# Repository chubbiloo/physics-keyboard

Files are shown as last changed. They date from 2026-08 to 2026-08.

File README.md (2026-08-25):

# physics-keyboard

A 33-key mechanical keyboard for writing physics and math.

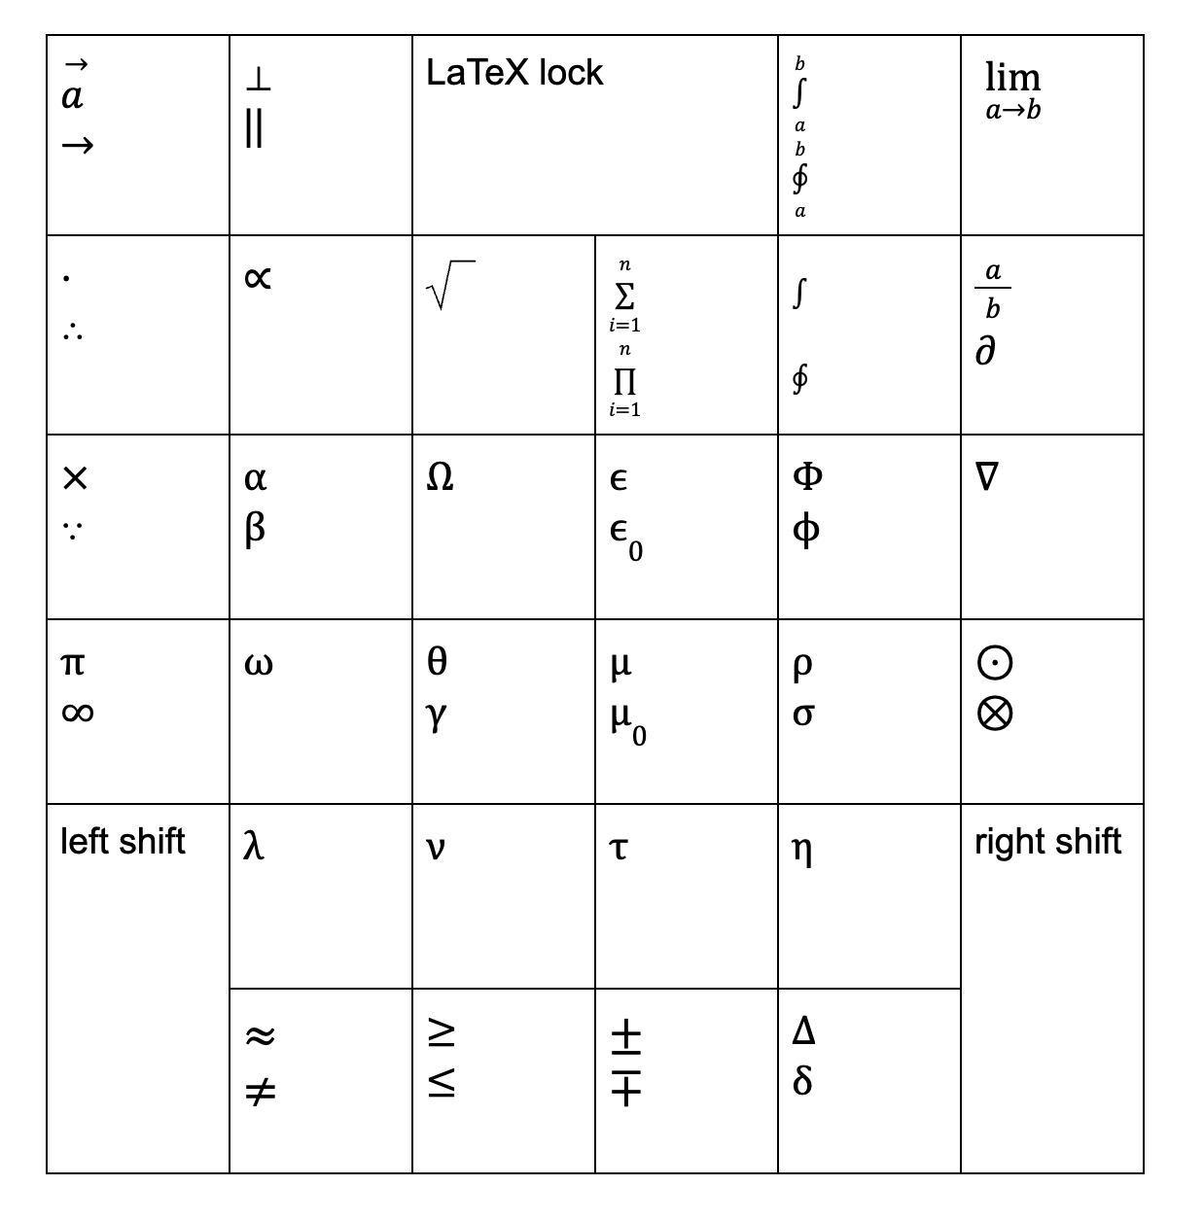
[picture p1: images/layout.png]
Layout


## Features
- Greek letter input
- Math symbol input
- Left and right shift keys allow for 53 unique characters
- Caps Lock-like key allows switching between LaTeX and plain unicode output
- Compact square shape; similar in size to a large numpad/macropad

[BOM](bom.csv)

## Tools
- PCB design: KiCad, marbastlib
- Enclosure CAD: OnShape
- Keycap lettering: Tinkercad
- Firmware: RMK 

## Motivation
In our last years of high school, we wrote several lab reports in IB Physics which required us to input mathematical equations. We built this keyboard to make that process easier, in our classes in university.

## What we learned
Before this project, we wrote our formulae in the Google Docs equation editor. This project helped us learn LaTeX, a faster and more advanced tool than what we used previously. We also learned PCB design, including best practices for routing and design rule checking.

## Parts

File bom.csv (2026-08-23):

Item | Unit Price | Count | Total Price | Link | Notes
1N4148 diode | 0.089 | 33 | 2.94 | https://www.digikey.ca/en/products/detail/onsemi/1N4148/458603
Keychron K Pro Mint switch |  | 110 | 29.99 | https://www.canadacomputers.com/en/keyboard-switches/261218/keychron-keychron-k-pro-switch-mint-110pcs-g149.html
Raspberry Pi Pico | 6.83 | 1 | 6.83 | https://www.digikey.ca/en/products/detail/raspberry-pi/SC0915/13624793
Stabilizers (7 x 2u, 1 x 6.25u) | 22.66 | 1 | 21.79 | https://www.aliexpress.com/item/1005005533734240.html
M2 heatset inserts (OD 3.5mm, L 4mm) |  | 50 | 3.16 | https://www.aliexpress.com/item/1005007946200223.html
20-pin header | 0.45 | 2 | 0.90 | https://www.digikey.ca/en/products/detail/same-sky-formerly-cui-devices/SSK01-MPH-254-A20/28772188
PCB |  | 5 | 16.94 |  | Ordered from JLCPCB
JLCPCB discounts |  |  | -13.97 |  | By applying coupon and ordering on desktop app
Aliexpress discounts |  |  | -4.00 |  | Promo code "IFP5UVCD"
JLCPCB shipping |  |  | 12.98
Digikey shipping |  |  | 15.00
Aliexpress shipping |  |  | 1.99
Subtotal |  |  | 92.56
Total including 13% HST |  |  | 104.59
All prices in CAD

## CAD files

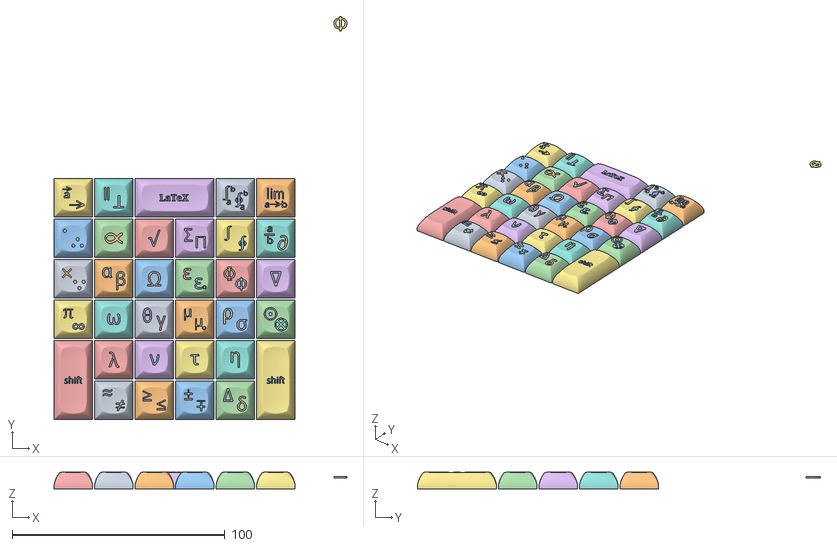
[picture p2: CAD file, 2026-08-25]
keycap-lettering/tinker.obj
137.8 x 189.6 x 7.91
obj_0
obj_1
obj_2
obj_3
obj_4
obj_5
obj_6
obj_7
obj_8
obj_9
obj_10
obj_11
obj_12
obj_13
obj_14
obj_15
obj_16
obj_17
obj_18
obj_19
obj_20
obj_21
obj_22
obj_23
obj_24
obj_25
obj_26
obj_27
obj_28
obj_29
obj_30
obj_31
obj_32
obj_33
obj_34
obj_35
obj_36
obj_37
obj_38
obj_39
obj_40
obj_41
obj_42
obj_43
obj_44
obj_45
obj_46
obj_47
obj_48
obj_49
obj_50
obj_51
obj_52
obj_53
obj_54
obj_55
obj_56
obj_57
obj_58
obj_59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

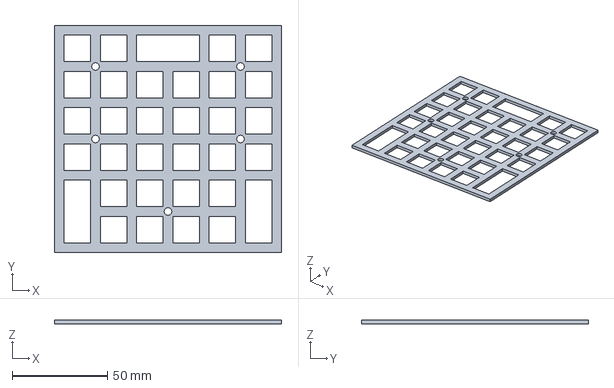
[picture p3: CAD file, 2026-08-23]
physics-keyboard-plate.step
119.3 x 119.3 x 2.00 mm

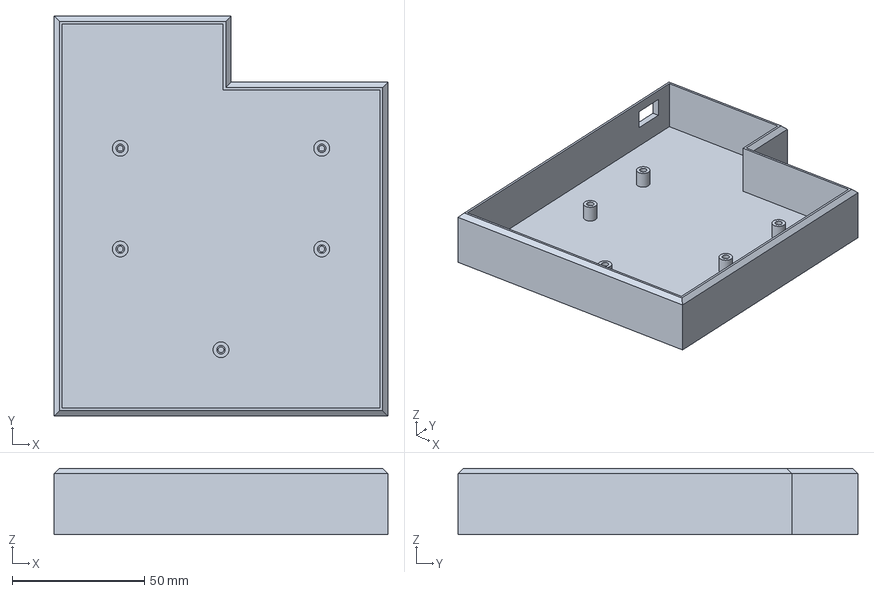
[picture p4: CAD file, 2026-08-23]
physics-keyboard-case.step
126.3 x 151.3 x 25.0 mm

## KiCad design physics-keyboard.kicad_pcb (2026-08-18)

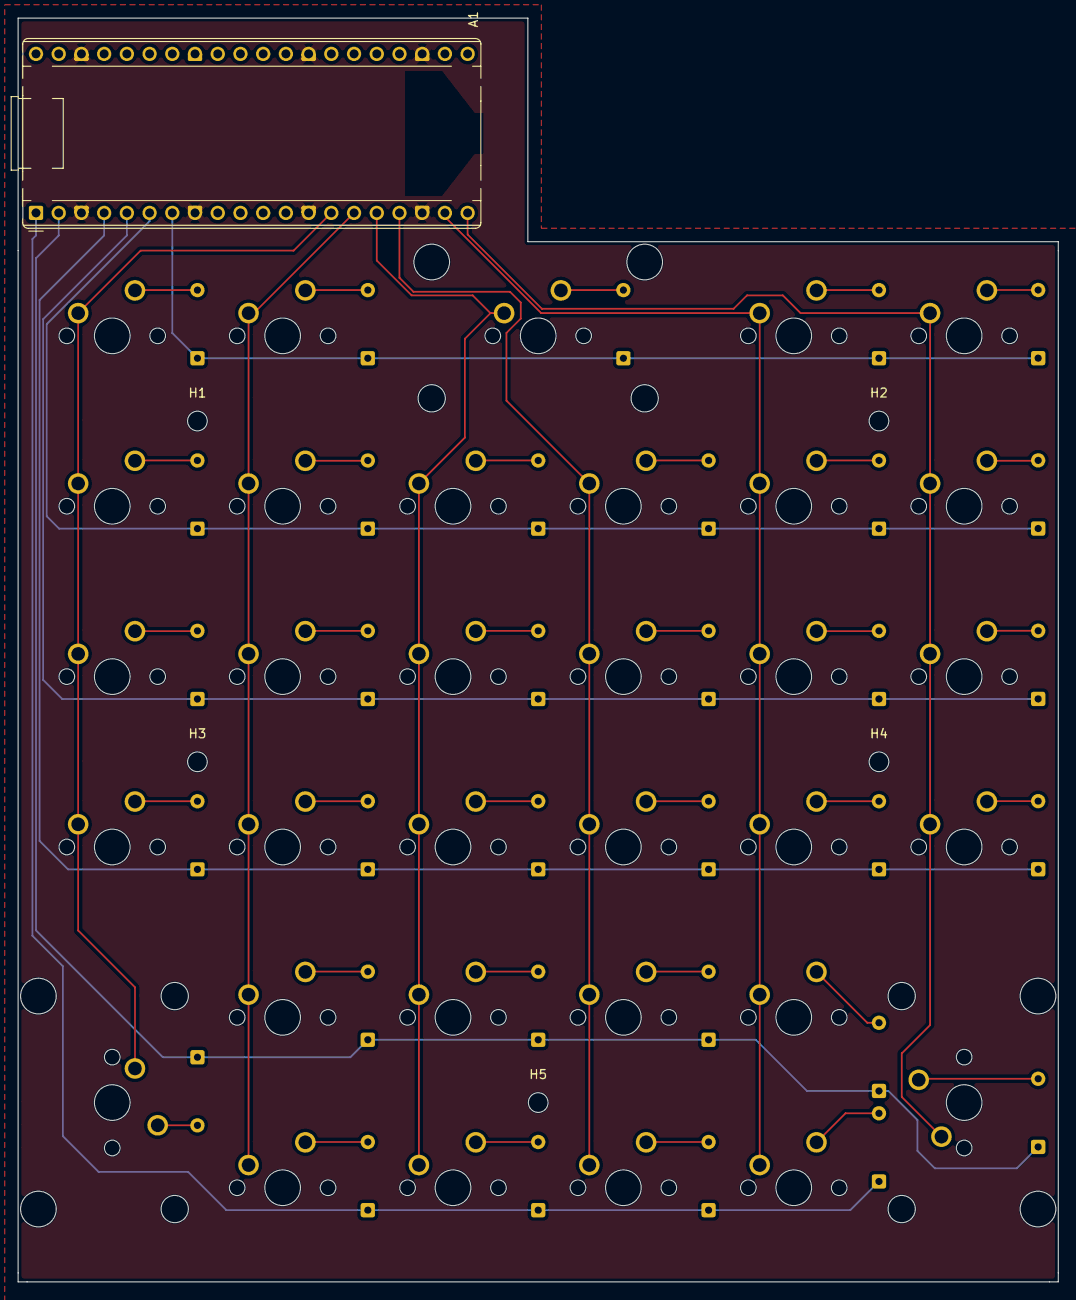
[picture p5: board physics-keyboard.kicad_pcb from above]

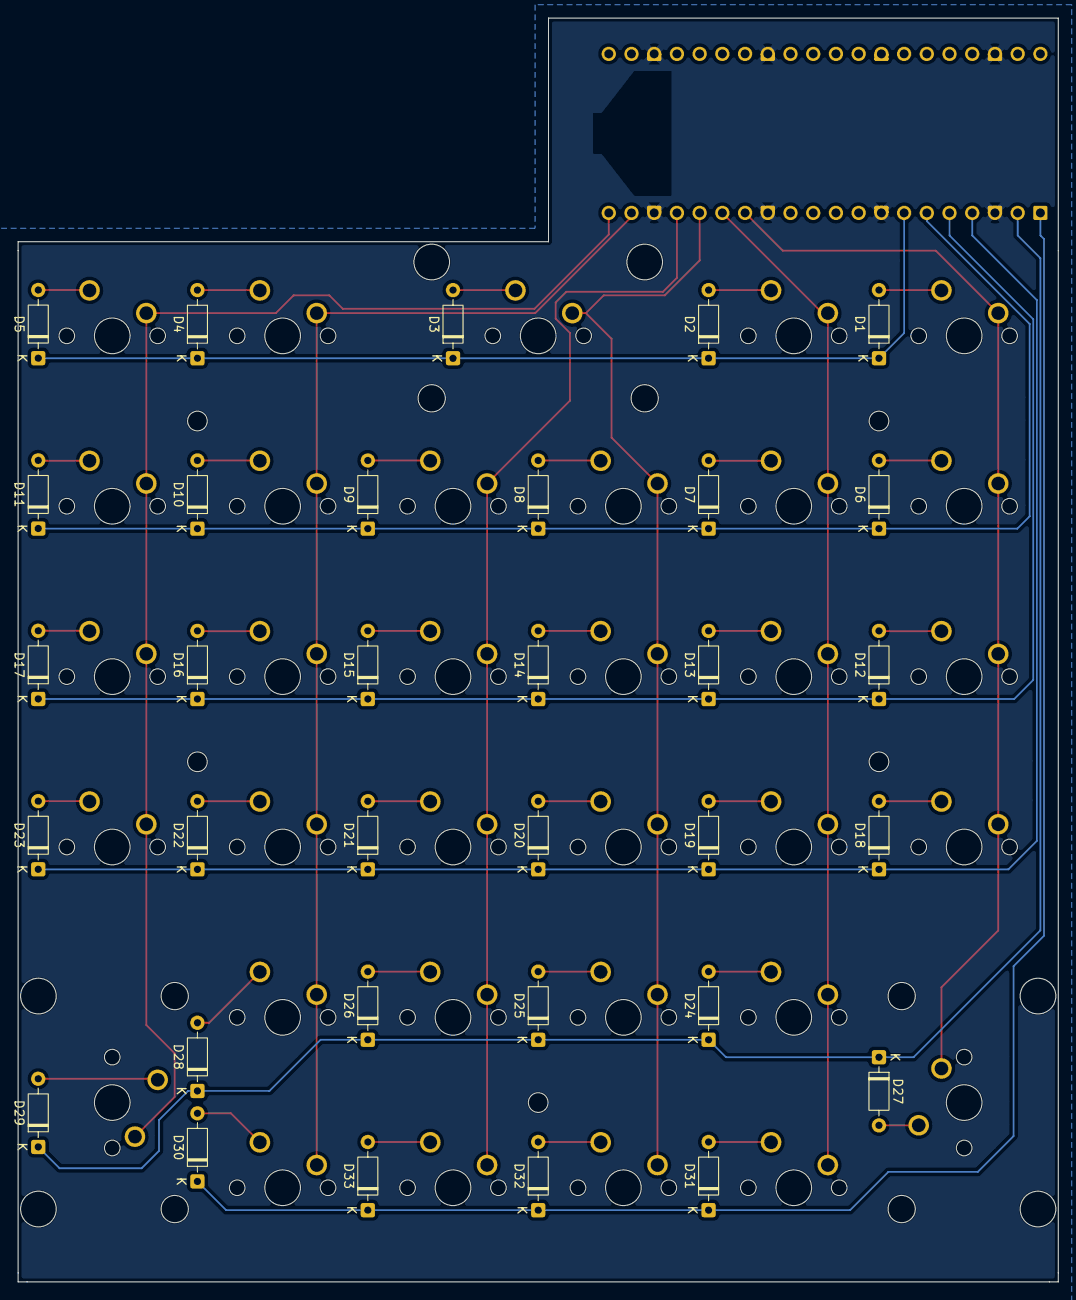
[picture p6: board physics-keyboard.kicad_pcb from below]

Board: 2 copper layers, 116.3 x 141.3 mm, 75 parts (33 on the bottom side), 46 nets.

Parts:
A1: RaspberryPi_Pico; RaspberryPi_Pico_Common_THT
D1, D2, D3, D4, D5, D6, D7, D8, D9, D10, D11, D12, D13, D14, D15, D16, D17, D18, D19, D20, D21, D22, D23, D24, D25, D26, D27, D28, D29, D30, D31, D32, D33: 1N4148; D_DO-35_SOD27_P7.62mm_Horizontal
H1, H2, H3, H4, H5: MountingHole; MountingHole_2.2mm_M2
S1, S2, S3: MX_stab; STAB_MX_2u
SW1, SW2, SW3, SW4, SW5, SW6, SW7, SW8, SW9, SW10, SW11, SW12, SW13, SW14, SW15, SW16, SW17, SW18, SW19, SW20, SW21, SW22, SW23, SW24, SW25, SW26, SW27, SW28, SW29, SW30, SW31, SW32, SW33: SW_Push; SW_MX_1u

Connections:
/COL0: A1.14 (GPIO10), SW1.1, SW6.1, SW12.1, SW18.1, SW28.1
/COL1: A1.15 (GPIO11), SW2.1, SW7.1, SW13.1, SW19.1, SW24.1, SW30.1
/COL2: A1.16 (GPIO12), SW3.1, SW8.1, SW14.1, SW20.1, SW25.1, SW31.1
/COL3: A1.17 (GPIO13), SW9.1, SW15.1, SW21.1, SW26.1, SW32.1
/COL4: A1.19 (GPIO14), SW4.1, SW10.1, SW16.1, SW22.1, SW27.1, SW33.1
/COL5: A1.20 (GPIO15), SW5.1, SW11.1, SW17.1, SW23.1, SW29.1
/ROW0: A1.7 (GPIO5), D1.1 (K), D2.1 (K), D3.1 (K), D4.1 (K), D5.1 (K)
/ROW1: A1.6 (GPIO4), D6.1 (K), D7.1 (K), D8.1 (K), D9.1 (K), D10.1 (K), D11.1 (K)
/ROW2: A1.5 (GPIO3), D12.1 (K), D13.1 (K), D14.1 (K), D15.1 (K), D16.1 (K), D17.1 (K)
/ROW3: A1.4 (GPIO2), D18.1 (K), D19.1 (K), D20.1 (K), D21.1 (K), D22.1 (K), D23.1 (K)
/ROW4: A1.2 (GPIO1), D24.1 (K), D25.1 (K), D26.1 (K), D27.1 (K), D28.1 (K), D29.1 (K)
/ROW5: A1.1 (GPIO0), D30.1 (K), D31.1 (K), D32.1 (K), D33.1 (K)
unnamed: A1.3 (GND), A1.8 (GND), A1.13 (GND), A1.18 (GND), A1.23 (GND), A1.28 (GND), A1.38 (GND)
unnamed: D1.2 (A), SW1.2
unnamed: D2.2 (A), SW2.2
unnamed: D6.2 (A), SW6.2
unnamed: D7.2 (A), SW7.2
unnamed: D12.2 (A), SW12.2
unnamed: D18.2 (A), SW18.2
unnamed: D8.2 (A), SW8.2
unnamed: D9.2 (A), SW9.2
unnamed: D10.2 (A), SW10.2
unnamed: D11.2 (A), SW11.2
unnamed: D13.2 (A), SW13.2
unnamed: D14.2 (A), SW14.2
unnamed: D15.2 (A), SW15.2
unnamed: D16.2 (A), SW16.2
unnamed: D17.2 (A), SW17.2
unnamed: D19.2 (A), SW19.2
unnamed: D20.2 (A), SW20.2
unnamed: D21.2 (A), SW21.2
unnamed: D22.2 (A), SW22.2
unnamed: D23.2 (A), SW23.2
unnamed: D24.2 (A), SW24.2
unnamed: D25.2 (A), SW25.2
unnamed: D26.2 (A), SW26.2
unnamed: D28.2 (A), SW27.2
unnamed: D3.2 (A), SW3.2
unnamed: D31.2 (A), SW30.2
unnamed: D32.2 (A), SW31.2
unnamed: D33.2 (A), SW32.2
unnamed: D30.2 (A), SW33.2
unnamed: D4.2 (A), SW4.2
unnamed: D27.2 (A), SW28.2
unnamed: D5.2 (A), SW5.2
unnamed: D29.2 (A), SW29.2

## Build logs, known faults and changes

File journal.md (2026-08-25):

## Journal

By [Antony Zhang](github.com/chubbiloo) (A) and [Ryan Liu](github.com/noir-depresso) (R)

8/11 (1 hour)
together: Today we started brainstorming what keys we wanted to include in the keyboard. We wanted to have it be an add-on (like a macropad) to a standard keyboard, so we decided to exclude symbols (e.g. letters) that could already be typed easily. By referring to a physics formula booklet, we started building this table:

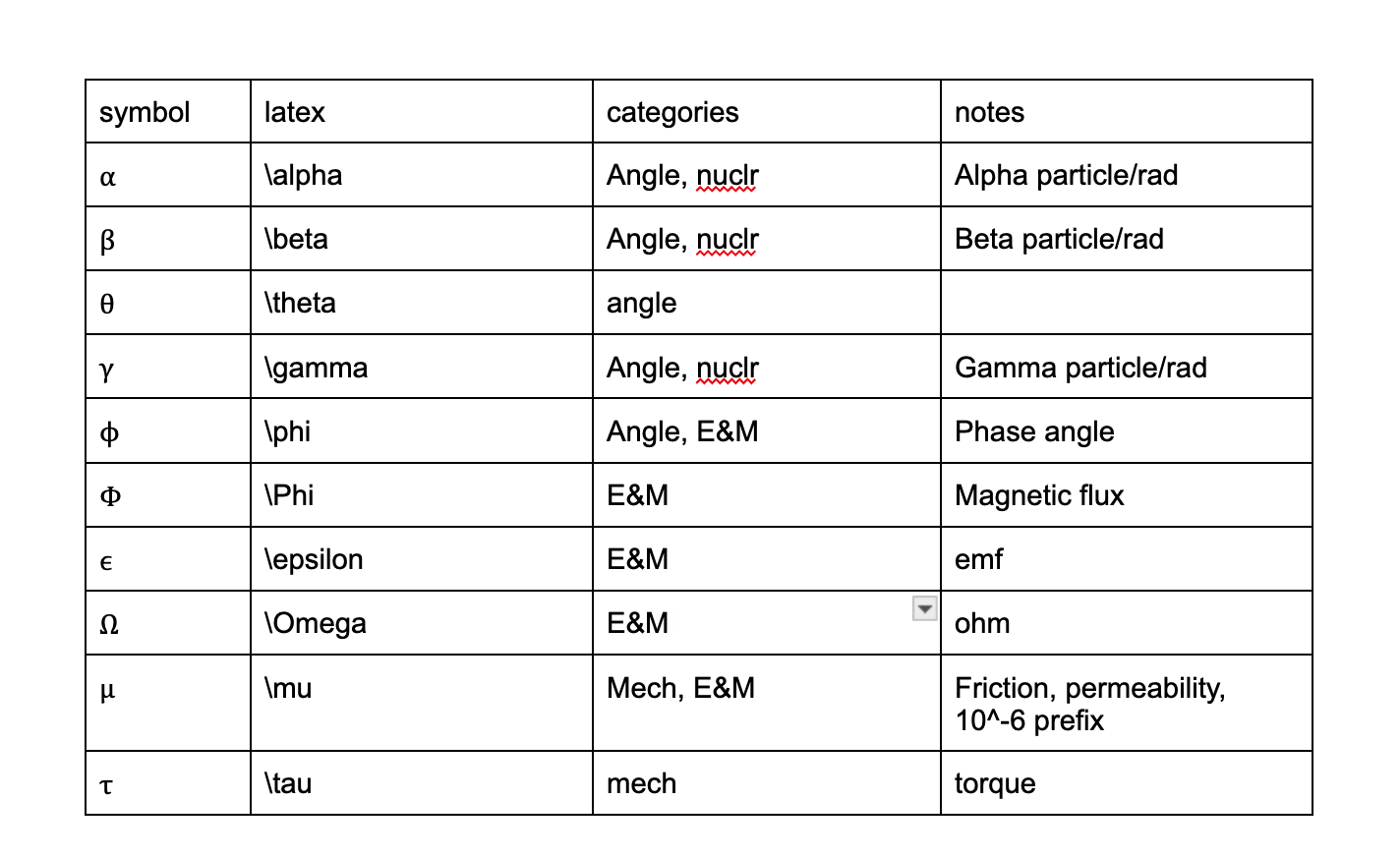
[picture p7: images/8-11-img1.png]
Character table


8/11 (2 hours)
A: I finished making the list of symbols. We have 43 in total. We will add two shift keys to the keyboard to reduce the amount of keys needed. I also classified each symbol so that R can arrange them so that similar symbols are clustered together. 

8/11 (1 hour)
R: came up with draft designs of the keyboard, how keys are arranged and activated. also how the keyboard itself looks like.
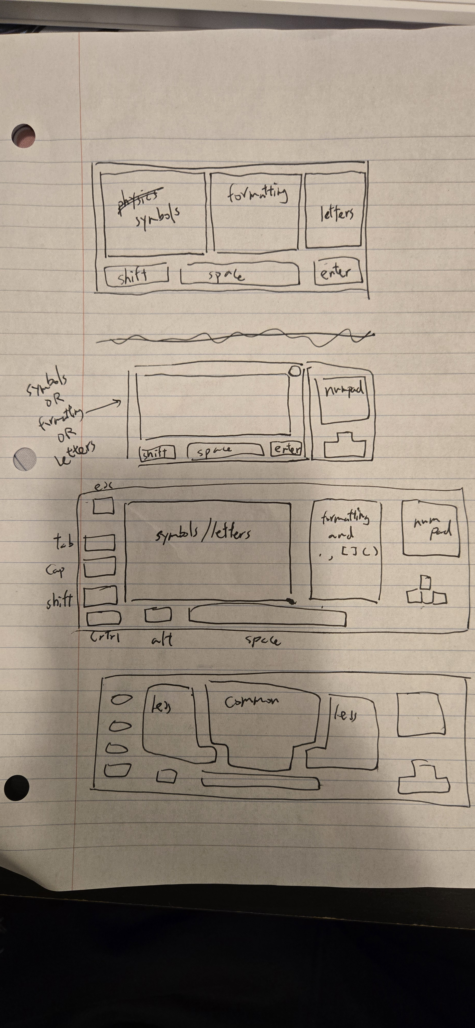
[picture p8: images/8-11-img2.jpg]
design 1


8/12 (2 hours)
A: set up KiCad, finished schematic and assigned footprints. The key matrix uses 12 GPIO pins for 6 cols and 6 rows. improved keyboard design
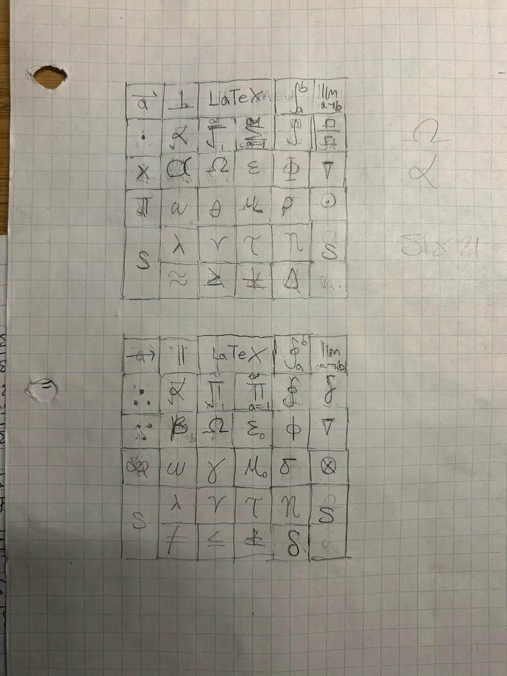
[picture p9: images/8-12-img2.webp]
design 2


8/12 (2 hours)
A: started working on PCB, setting the grid spacing to a factor of 19.05mm allowed alignment of keys by snapping to the grid. the PCB is square with each side being (19.05*6)mm long. A 55x25mm protrusion makes space for mounting the Pico.
Originally, the Pico was meant to be centred at the top side of the keys, but we moved it to the upper left for improved microUSB port accessibility.

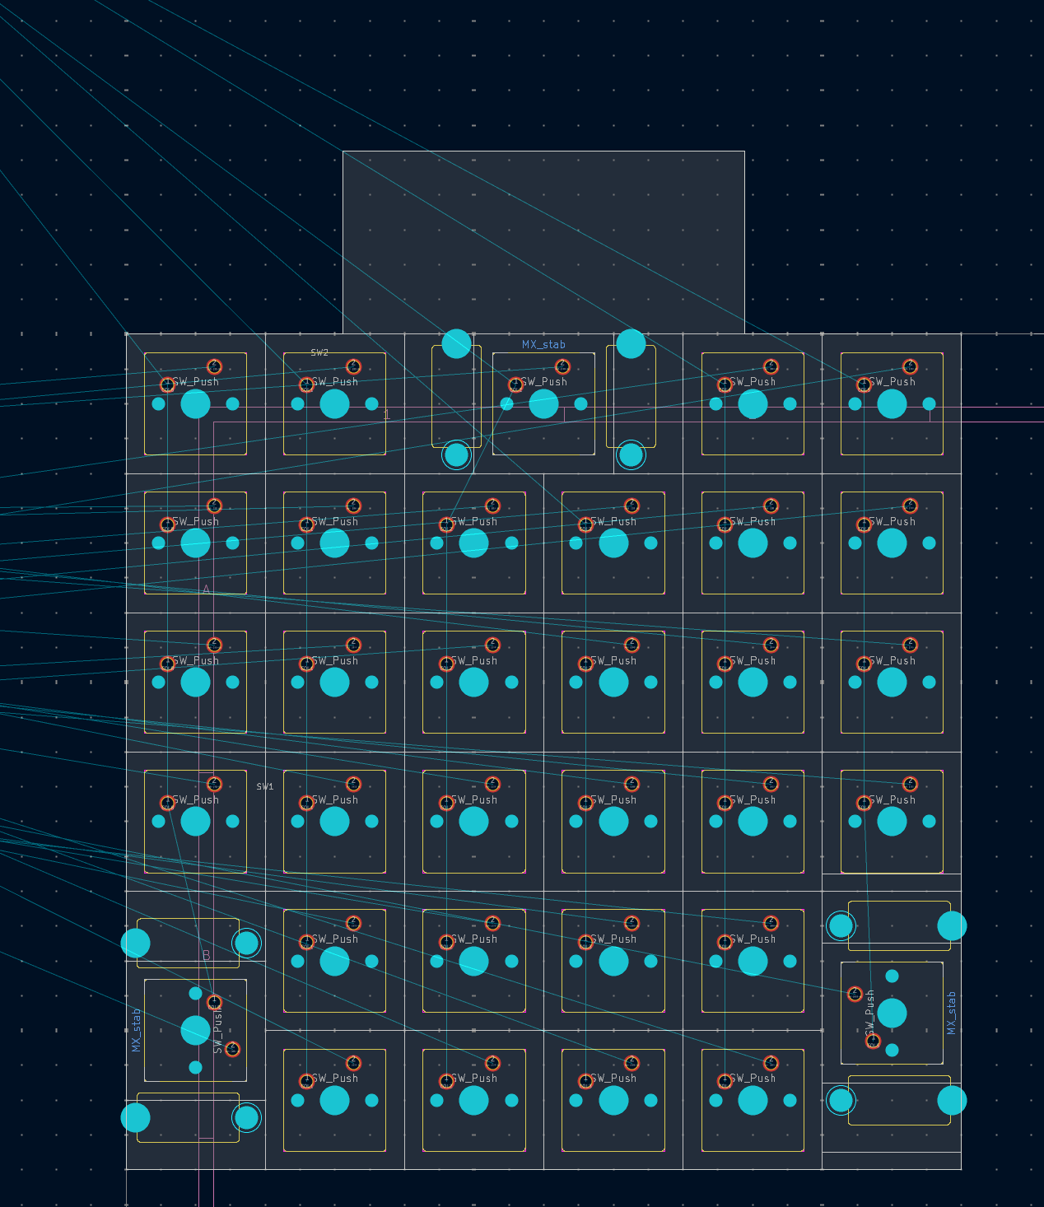
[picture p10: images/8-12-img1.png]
Placement of switch footprints


8/13 (.5 hours)
We called in the morning to figure out how to add text onto keycaps in Tinkercad. We imported a blank keycap from Printables, added text and aligned the text with the keys so that the symbol is embossed on top of it

8/13 (3 hours)
R: imported key cap design and extruded symbols in tinkercad, learning how tinkercad works in the process
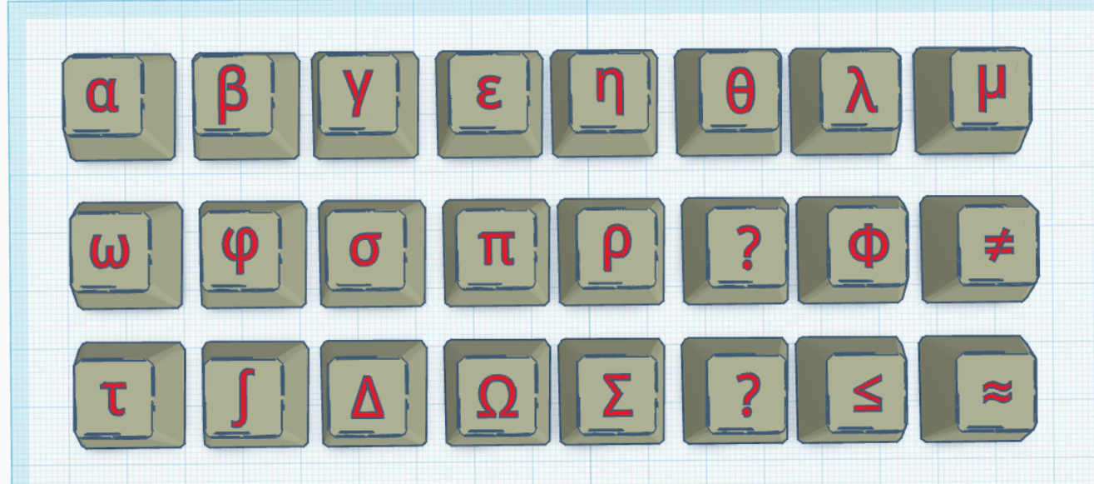
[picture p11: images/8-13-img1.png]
key cap design 1


8/14 (1.5 hours)
A: started routing the PCB. Adjusted pin mapping so that traces do not need to cross.
We also decided to add a right shift key and Unicode/LaTeX toggle key, expanding the keyboard to a 6x6 grid today
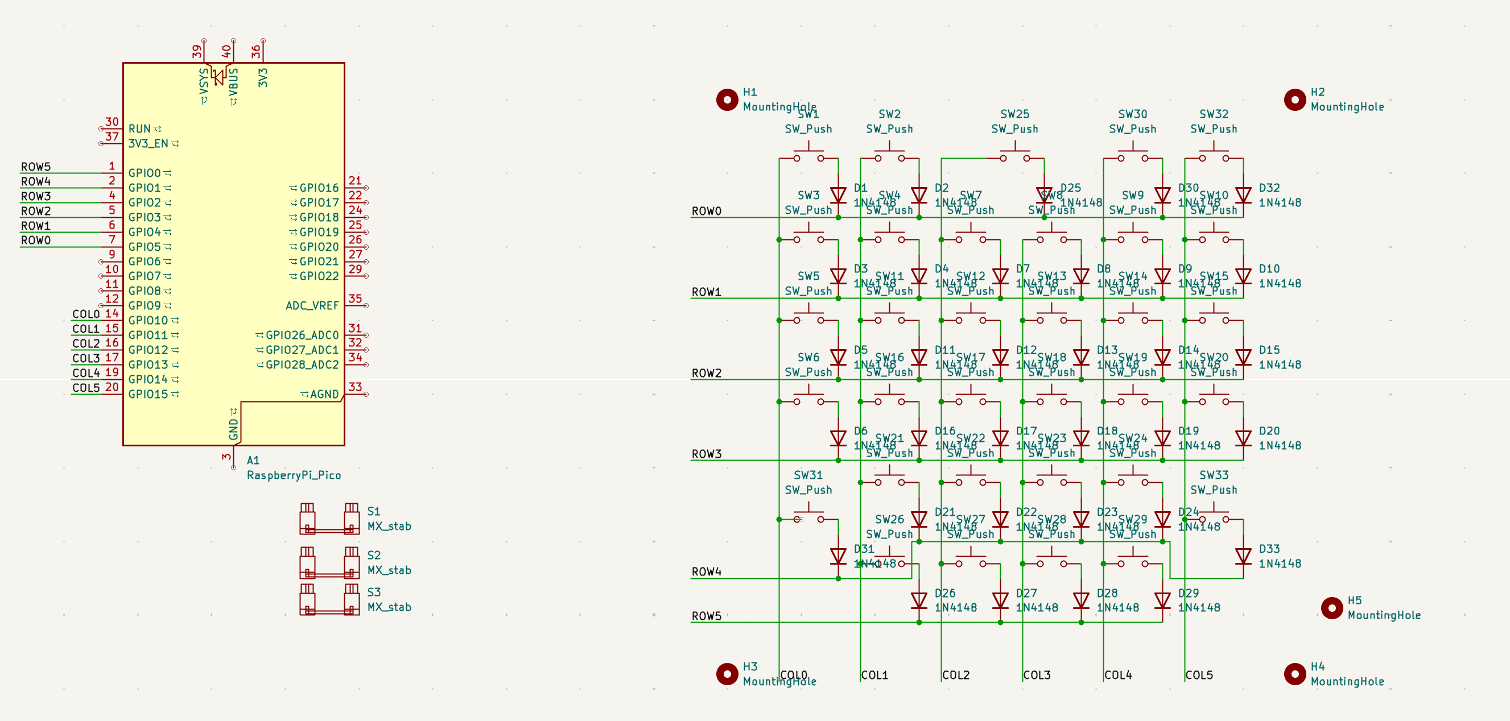
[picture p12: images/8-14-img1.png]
Final schematic

Schematic after pin remapping

8/14 (3 hours)
R: nearly finished key cap design in Tinkercad. Some special characters don't render properly and need to be made from other characters (or imported as svg)
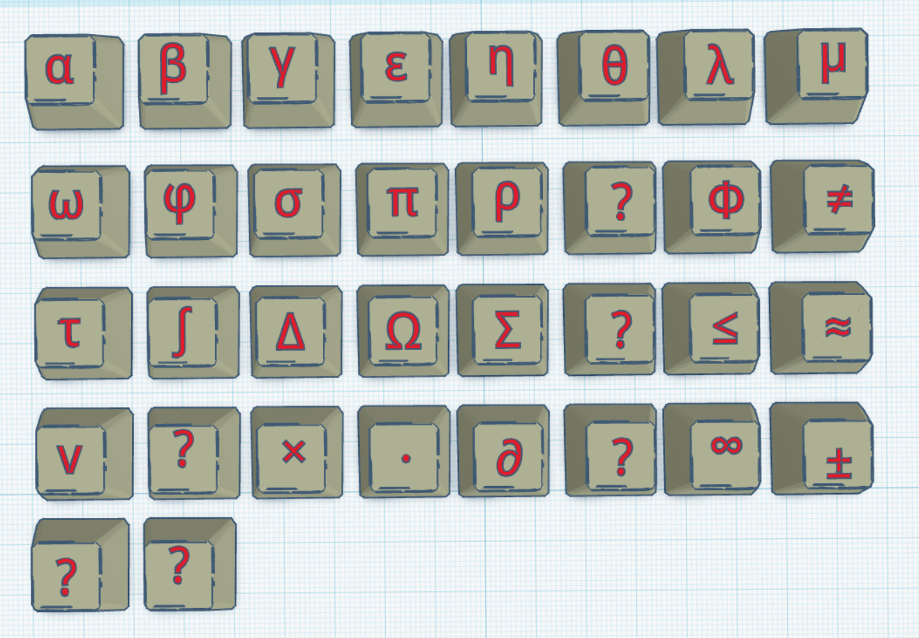
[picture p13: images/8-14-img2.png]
key cap design 2


8/16 (3 hours)
R: making the keyboard case in onshape and learning how to use onshape
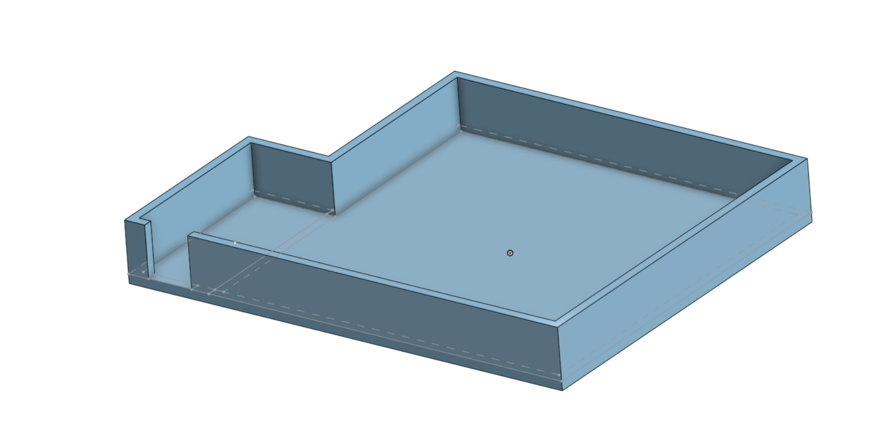
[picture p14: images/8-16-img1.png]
keyboard case 1


8/17 (4 hours)
A: finished routing the PCB. Added a 1 mm margin to all sides of the PCB to fit stabilizer mounting holes. Moved the Pico slightly so that microUSB port sticks out. Added ground fill to both faces, ran DRC, checked 3D model

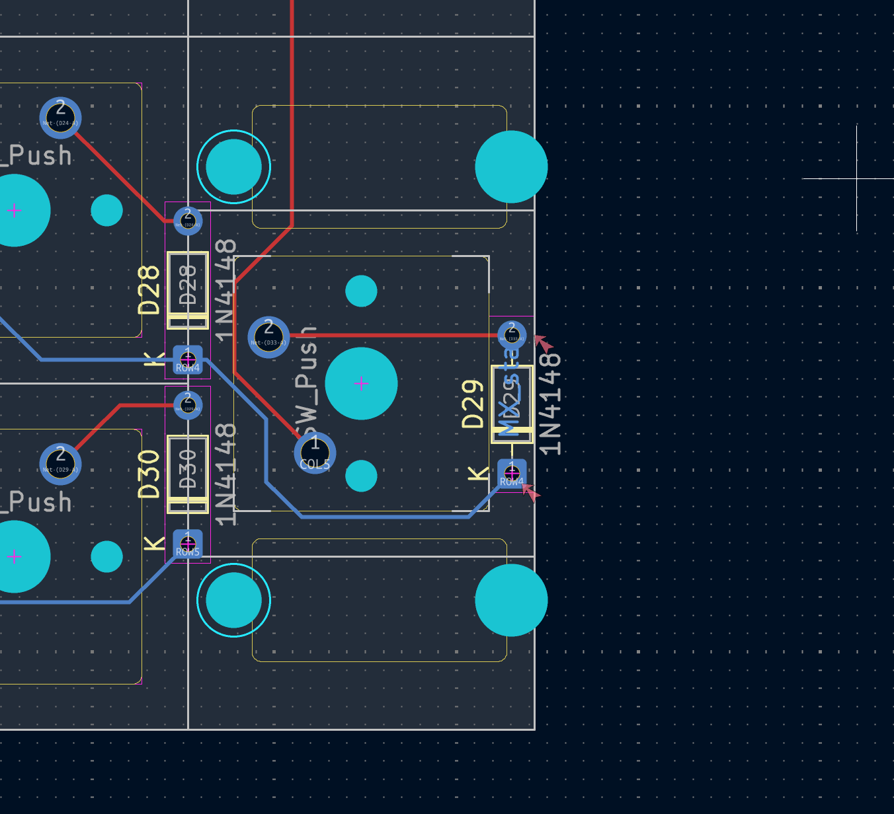
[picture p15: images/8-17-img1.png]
Stabilizer mounting holes not fitting inside original boundary

Stabilizer mounting holes not fitting within original boundary

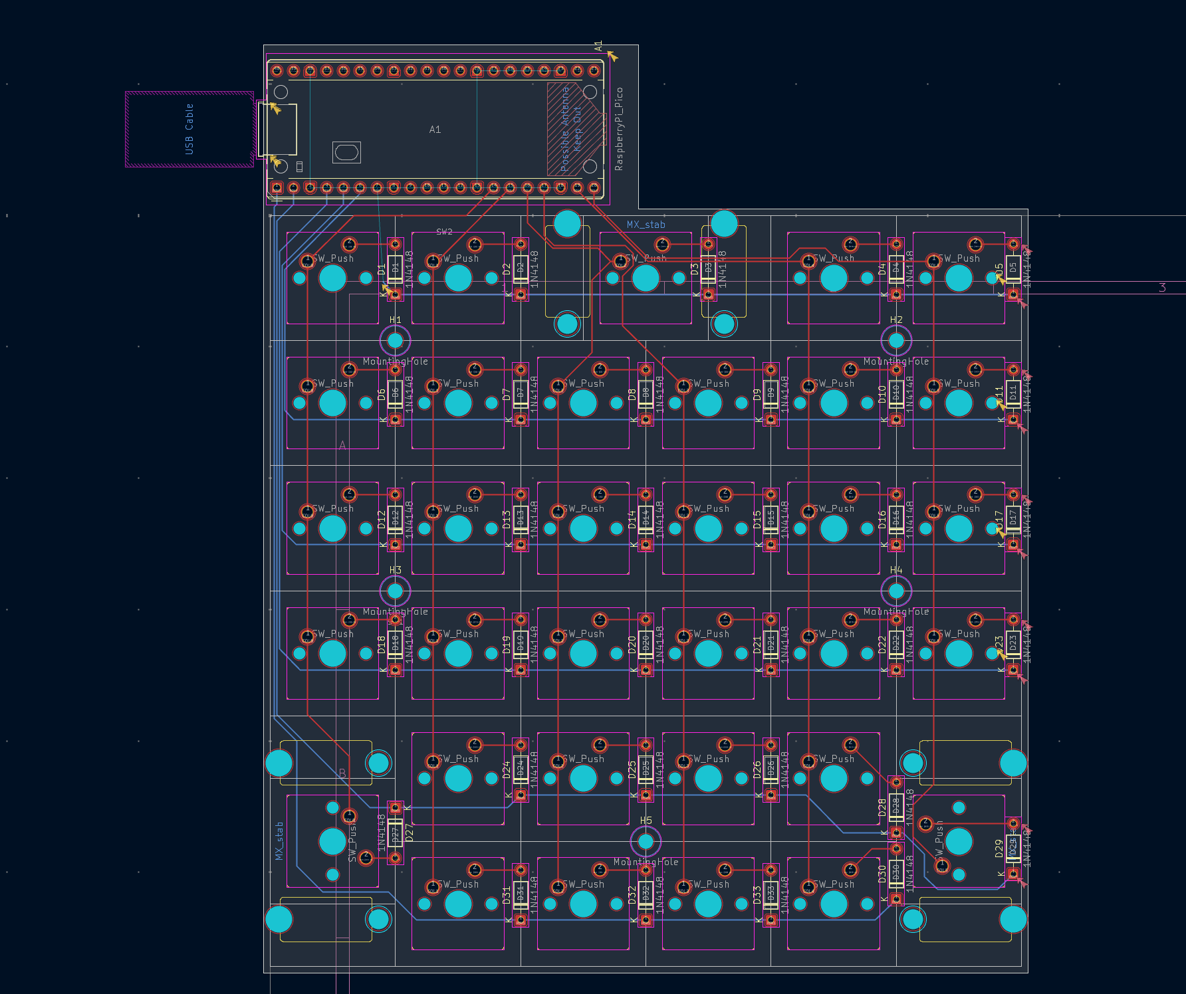
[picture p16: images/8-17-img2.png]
Final PCB routing

Completed PCB routing. Red arrows showed DRC violation (insufficient spacing from edge for diodes) which was fixed by adding margin.

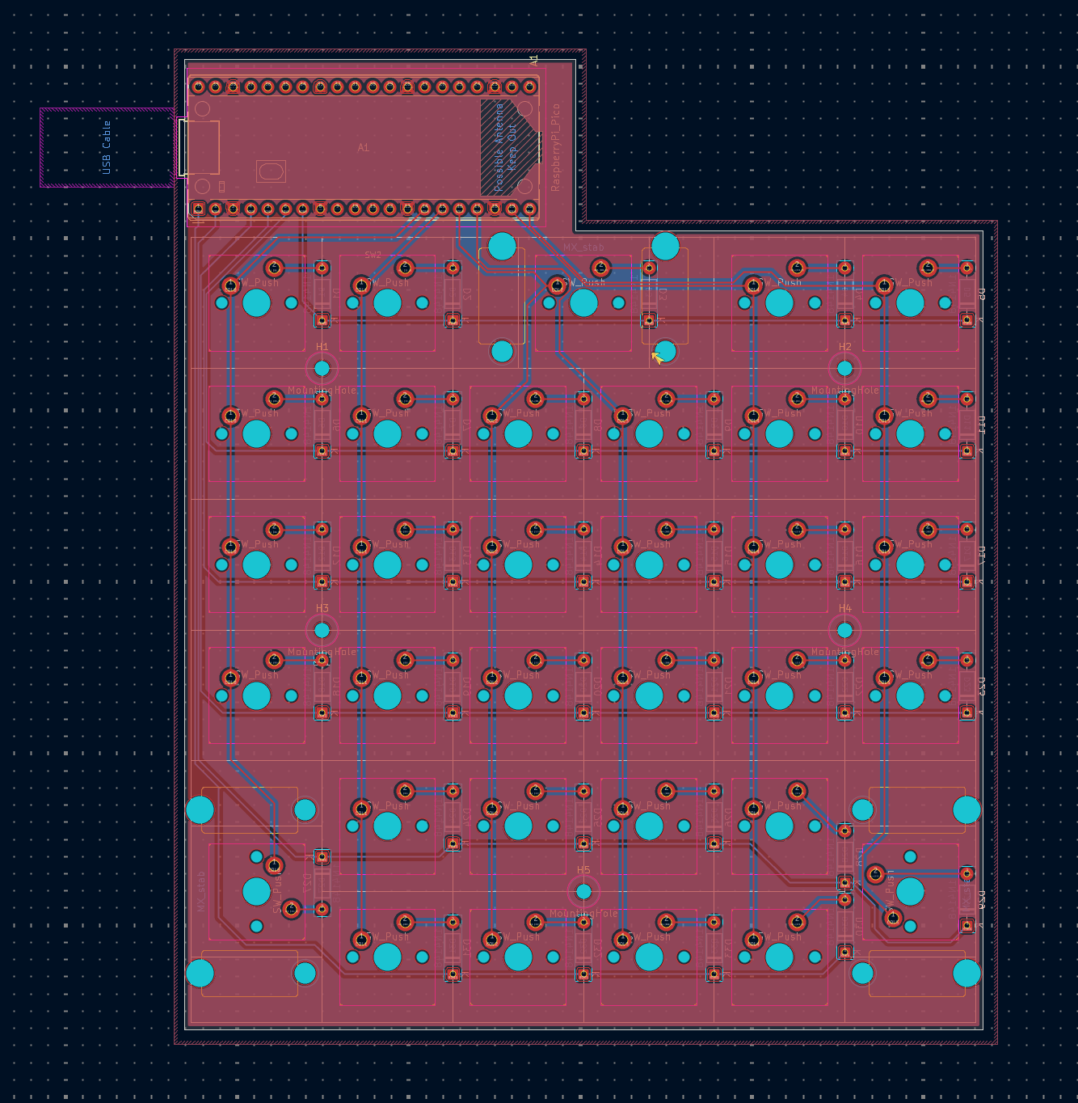
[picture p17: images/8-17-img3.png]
Final PCB with ground fill added

Final PCB

8/17 (2 hours)
R: made the keyboard plate in OnShape with linear pattern tool
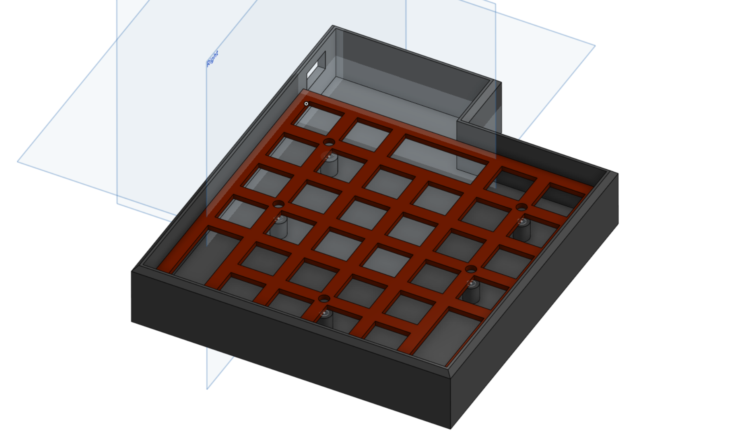
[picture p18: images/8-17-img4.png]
keyboard case 2


8/18 (3 hours)
A: drafted the README and BOM

8/18 (4 hours)
together: imported step model of PCB to OnShape, designed case with standoffs for tray mounting that fit threaded inserts. They fit M2x8mm screws. The 5 holes are 3.2mm in diameter x 4mm long (insert portion) and 2.2x4mm (remaining portion). Mated all parts in assembly
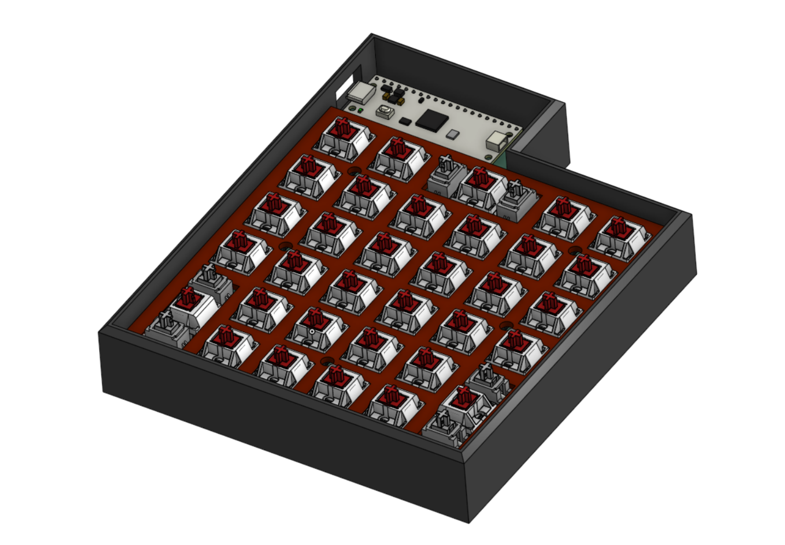
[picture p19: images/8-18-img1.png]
final cad 1

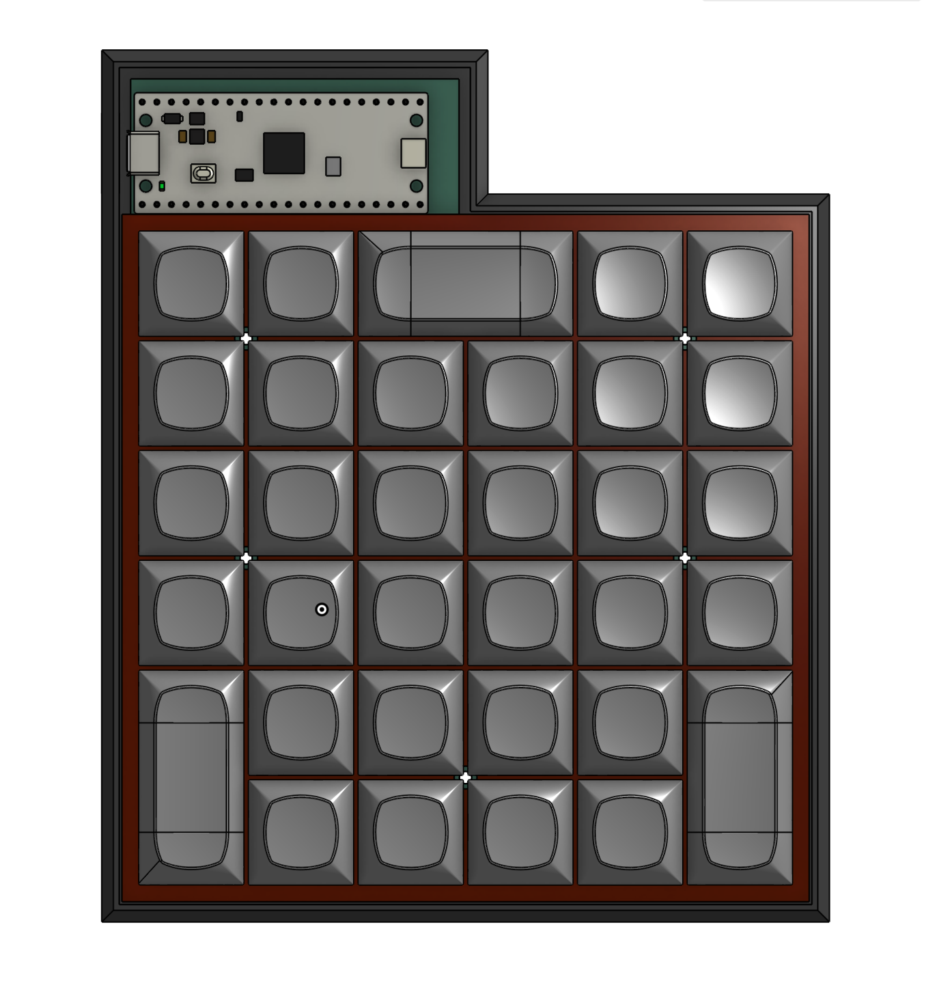
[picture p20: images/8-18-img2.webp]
final cad 2


8/18 (1 hour)
together: fixed lettering height; aligned lettering with DSA keycaps (our final choice)
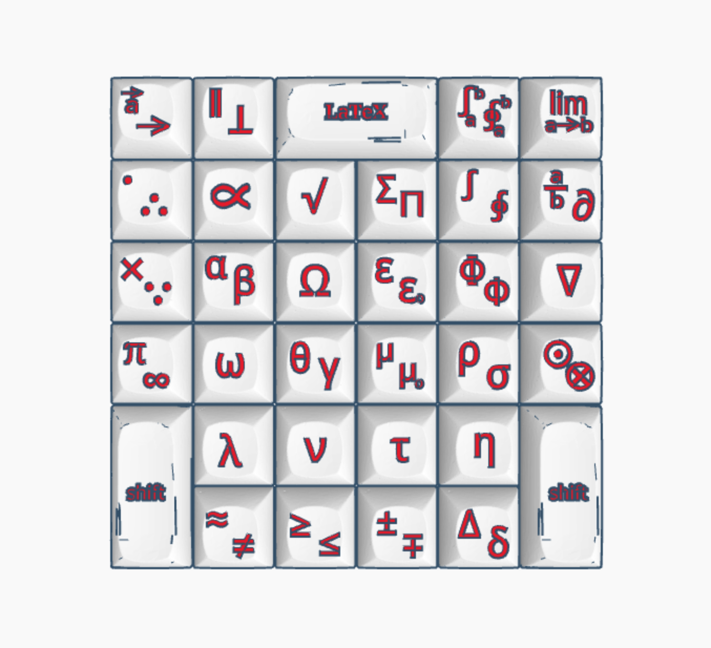
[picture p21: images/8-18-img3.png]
Keycap lettering


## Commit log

2026-08-18 Update journal with keycap and PCB design progress
2026-08-18 Enhance journal with PCB and keycap details
    Updated journal entries with additional details about PCB design and keycap text alignment.
2026-08-18 Enhance journal with images for PCB and keycap entries
    Added images to journal entries for PCB design and keycap text alignment.
2026-08-18 Add final PCB image to journal
2026-08-18 Update PCB routing and keyboard layout details
    Adjusted pin mapping for PCB routing and expanded keyboard layout to 6x6 grid. Added a right shift key and Unicode/LaTeX toggle key.
2026-08-18 Add tools section to README
    Added tools section with details on PCB design, CAD, and firmware.
2026-08-18 Update 'What we learned' section in README
    Expanded on the learning outcomes from the project, including PCB design.
2026-08-18 Add BOM link to README
2026-08-19 Add currency note to BOM CSV
    Added a new line for 'All prices in CAD' at the end of the file.
    [bom.csv]
2026-08-25 Revise key cap design status in journal
    Updated the status of the key cap design in Tinkercad to reflect current progress and issues with special character rendering.
2026-08-25 Revise 8/18 journal entry with additional details
    Updated journal entries for 8/18 to include BOM details and refined design specifications.
2026-10-23 Revise journal with detailed entries and images
    Updated journal entries with detailed descriptions of tasks, time spent, and images for various stages of keyboard design and PCB routing.
2026-11-02 Update CAD links in README.md
2026-11-02 Fix formatting of CAD links in README
2026-11-02 Update BOM with new items and price adjustments
